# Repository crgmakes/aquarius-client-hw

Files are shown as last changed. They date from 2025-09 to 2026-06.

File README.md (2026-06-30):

# Aquarius Client Hardware

All the source files for the client hardware.

# Software 

You will need [KiCad](https://kicad.org) to view and edit this design. Click [here](https://www.kicad.org/download/) to download.

You will also need all the associated libraries and models to drive the design if you want to make changes or view the 3D rendering:

https://github.com/crgmakes/kicad-library.git

Kicad MUST be configured properly to use all the files in this repo. Once you have Kicad installed, under Preferences->Configure Paths..., make the following entries:

1 - KICAD_USER_DIR -> set to the root location of where you placed the above repository.
2 - KICAD_USER_LIBRARY = ${KICAD_USER_DIR}/Library
3 - KICAD_USER_MODEL_DIR = ${KICAD_USER_LIBRARY}/models
4 - KICAD_USER_TEMPLATE_DIR	= ${KICAD_USER_LIBRARY}/templates	

Kicad will operate mostly normally if these are not set properly. You will notice an issue when you view the PCB in 3D mode.

***NOTE***: after makeing a release build in git, if your rendered 3D images are missing components, ensure the path to EVERY component model is set to ${KICAD_USER_MODEL_DIR}/<model name>.

Kicad sometimes replaces the variable with an expansion and that FAILS during the build process because the expanded variable is local and does not match the build environment.

---

THE DESIGN IS PROVIDED "AS IS" AND THE AUTHOR DISCLAIMS ALL WARRANTIES WITH REGARD TO THIS DESIGN INCLUDING ALL IMPLIED WARRANTIES OF MERCHANTABILITY AND FITNESS. IN NO EVENT SHALL THE AUTHOR BE LIABLE FOR ANY SPECIAL, DIRECT, INDIRECT, OR CONSEQUENTIAL DAMAGES OR ANY DAMAGES WHATSOEVER RESULTING FROM LOSS OF USE, DATA OR PROFITS, WHETHER IN AN ACTION OF CONTRACT, NEGLIGENCE OR OTHER TORTIOUS ACTION, ARISING OUT OF OR IN CONNECTION WITH THE USE OR PERFORMANCE OF THIS DESIGN.

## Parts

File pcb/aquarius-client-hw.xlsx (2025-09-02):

Prj: | aquarius-client-hw.csv |  |  |  | Board Qty: | 100
Co.: |  |  |  |  | Unit Cost: | $0.00
Prj date: | 2025-09-01 11:43:55 (file) |  |  |  | Total Cost: | $0.00
$ date: | 2025-09-01 12:00:02
Global Part Info
Refs | Value | Footprint | Manf# | Qty | Unit$ | Ext$
C_0603_1608Metric#1 | ??? - p1/2 | ??? | C17 | 100
C_0603_1608Metric#2 | ??? - p2/2 | ??? | C18 | 100
D_SOD523#1 | ??? - p1/8 | ??? | D11 | 100
D_SOD523#2 | ??? - p2/8 | ??? | D12 | 100
D_SOD523#3 | ??? - p3/8 | ??? | D13 | 100
D_SOD523#4 | ??? - p4/8 | ??? | D14 | 100
D_SOD523#5 | ??? - p5/8 | ??? | D15 | 100
D_SOD523#6 | ??? - p6/8 | ??? | D16 | 100
D_SOD523#7 | ??? - p7/8 | ??? | D9 | 100
D_SOD523#8 | ??? - p8/8 | ??? | D10 | 100
EVQQ2B02W0#1 | ??? - p1/2 | ??? | SW2 | 100
EVQQ2B02W0#2 | ??? - p2/2 | ??? | SW1 | 100
GCT_USB4105-GF-A | ??? | ??? | J3 | 100
JST_SH_BM03B-SRSS-TB_1x03-1MP_P1.00mm_Vertical#1 | ??? - p1/10 | ??? | J2 | 100
JST_SH_BM03B-SRSS-TB_1x03-1MP_P1.00mm_Vertical#2 | ??? - p2/10 | ??? | J15 | 100
JST_SH_BM03B-SRSS-TB_1x03-1MP_P1.00mm_Vertical#3 | ??? - p3/10 | ??? | J16 | 100
JST_SH_BM03B-SRSS-TB_1x03-1MP_P1.00mm_Vertical#4 | ??? - p4/10 | ??? | J11 | 100
JST_SH_BM03B-SRSS-TB_1x03-1MP_P1.00mm_Vertical#5 | ??? - p5/10 | ??? | J12 | 100
JST_SH_BM03B-SRSS-TB_1x03-1MP_P1.00mm_Vertical#6 | ??? - p6/10 | ??? | J4 | 100
JST_SH_BM03B-SRSS-TB_1x03-1MP_P1.00mm_Vertical#7 | ??? - p7/10 | ??? | J14 | 100
JST_SH_BM03B-SRSS-TB_1x03-1MP_P1.00mm_Vertical#8 | ??? - p8/10 | ??? | J1 | 100
JST_SH_BM03B-SRSS-TB_1x03-1MP_P1.00mm_Vertical#9 | ??? - p9/10 | ??? | J10 | 100
JST_SH_BM03B-SRSS-TB_1x03-1MP_P1.00mm_Vertical#10 | ??? - p10/10 | ??? | J13 | 100
JST_SH_BM04B-SRSS-TB_1x04-1MP_P1.00mm_Vertical#1 | ??? - p1/4 | ??? | J5 | 100
JST_SH_BM04B-SRSS-TB_1x04-1MP_P1.00mm_Vertical#2 | ??? - p2/4 | ??? | J17 | 100
JST_SH_BM04B-SRSS-TB_1x04-1MP_P1.00mm_Vertical#3 | ??? - p3/4 | ??? | J18 | 100
JST_SH_BM04B-SRSS-TB_1x04-1MP_P1.00mm_Vertical#4 | ??? - p4/4 | ??? | J6 | 100
JST_SH_BM08B-SRSS-TB_1x08-1MP_P1.00mm_Vertical#1 | ??? - p1/2 | ??? | J19 | 100
JST_SH_BM08B-SRSS-TB_1x08-1MP_P1.00mm_Vertical#2 | ??? - p2/2 | ??? | J9 | 100
JST_SH_SM04B-SRSS-TB_1x04-1MP_P1.00mm_Horizontal#1 | ??? - p1/2 | ??? | J7 | 100
JST_SH_SM04B-SRSS-TB_1x04-1MP_P1.00mm_Horizontal#2 | ??? - p2/2 | ??? | J8 | 100
LED_0603_1608Metric#1 | ??? - p1/2 | ??? | D7 | 100
LED_0603_1608Metric#2 | ??? - p2/2 | ??? | D8 | 100
LED_WS2812B-2020_PLCC4_2.0x2.0mm | ??? | ??? | D1 | 100
LTR303ALS1 | ??? | ??? | U3 | 100
PWSONN6 | ??? | ??? | U2 | 100
R_0603_1608Metric | ??? | ??? | R9 | 100
SON80P244X244X95-7N | ??? | ??? | U8 | 100
SOT666 | ??? | ??? | U4 | 100
SOTFL50P160X60-8N#1 | ??? - p1/2 | ??? | U5 | 100
SOTFL50P160X60-8N#2 | ??? - p2/2 | ??? | U6 | 100
TO2522 | ??? | ??? | U9 | 100
KiCost® v1.1.20

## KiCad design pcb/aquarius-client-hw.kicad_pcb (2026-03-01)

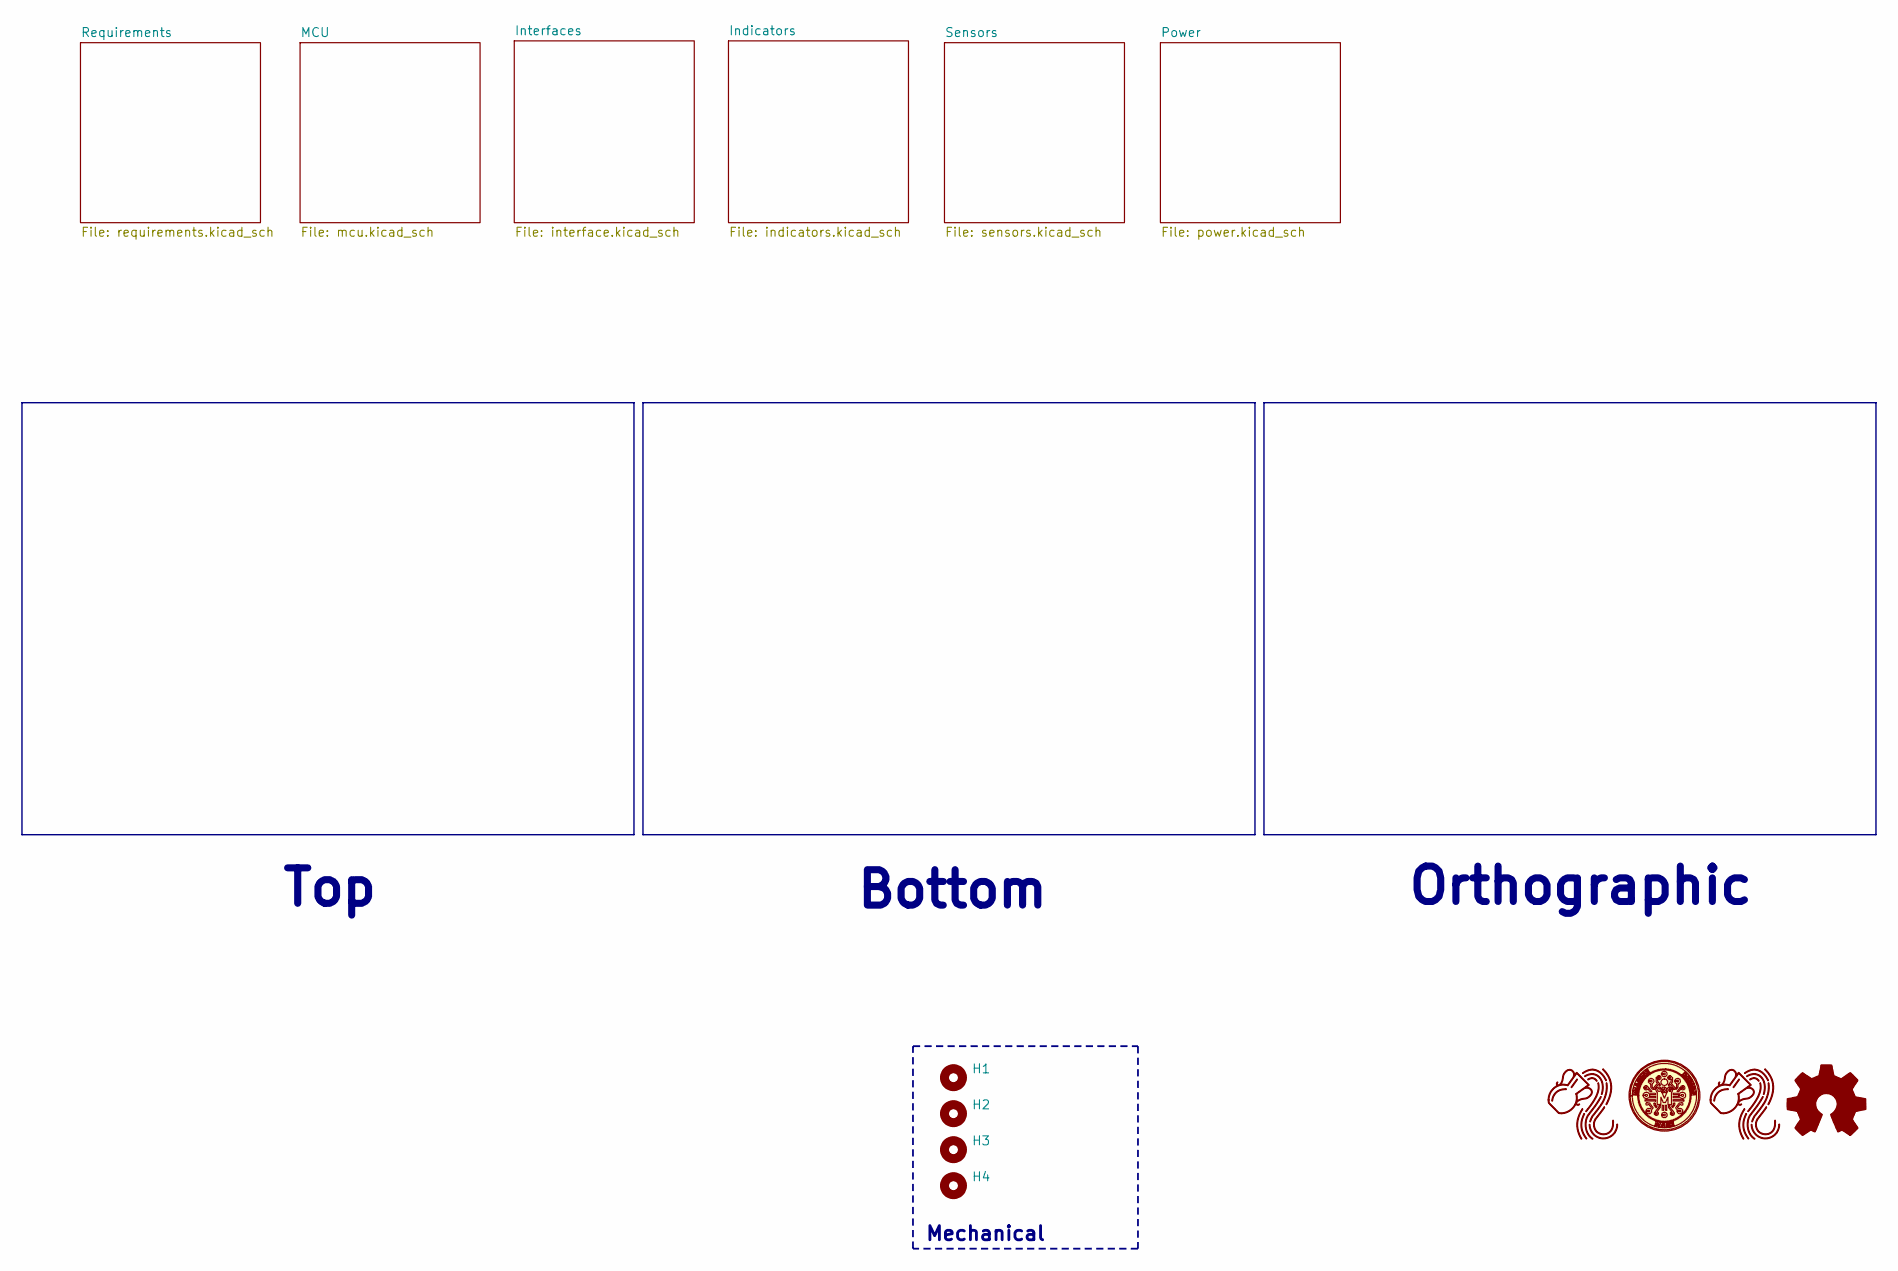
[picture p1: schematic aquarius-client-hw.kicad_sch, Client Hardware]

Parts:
H1, H2, H3, H4: MountingHole_3.2mm_M3_Pad_Via
LOGO1: CRGM Logo 5mm
LOGO2, LOGO3: Aquarius Logo 5mm
LOGO4: OSHW-Logo_5.7x6mm_SilkScreen

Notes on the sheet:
Mechanical
Bottom
Orthographic
Top

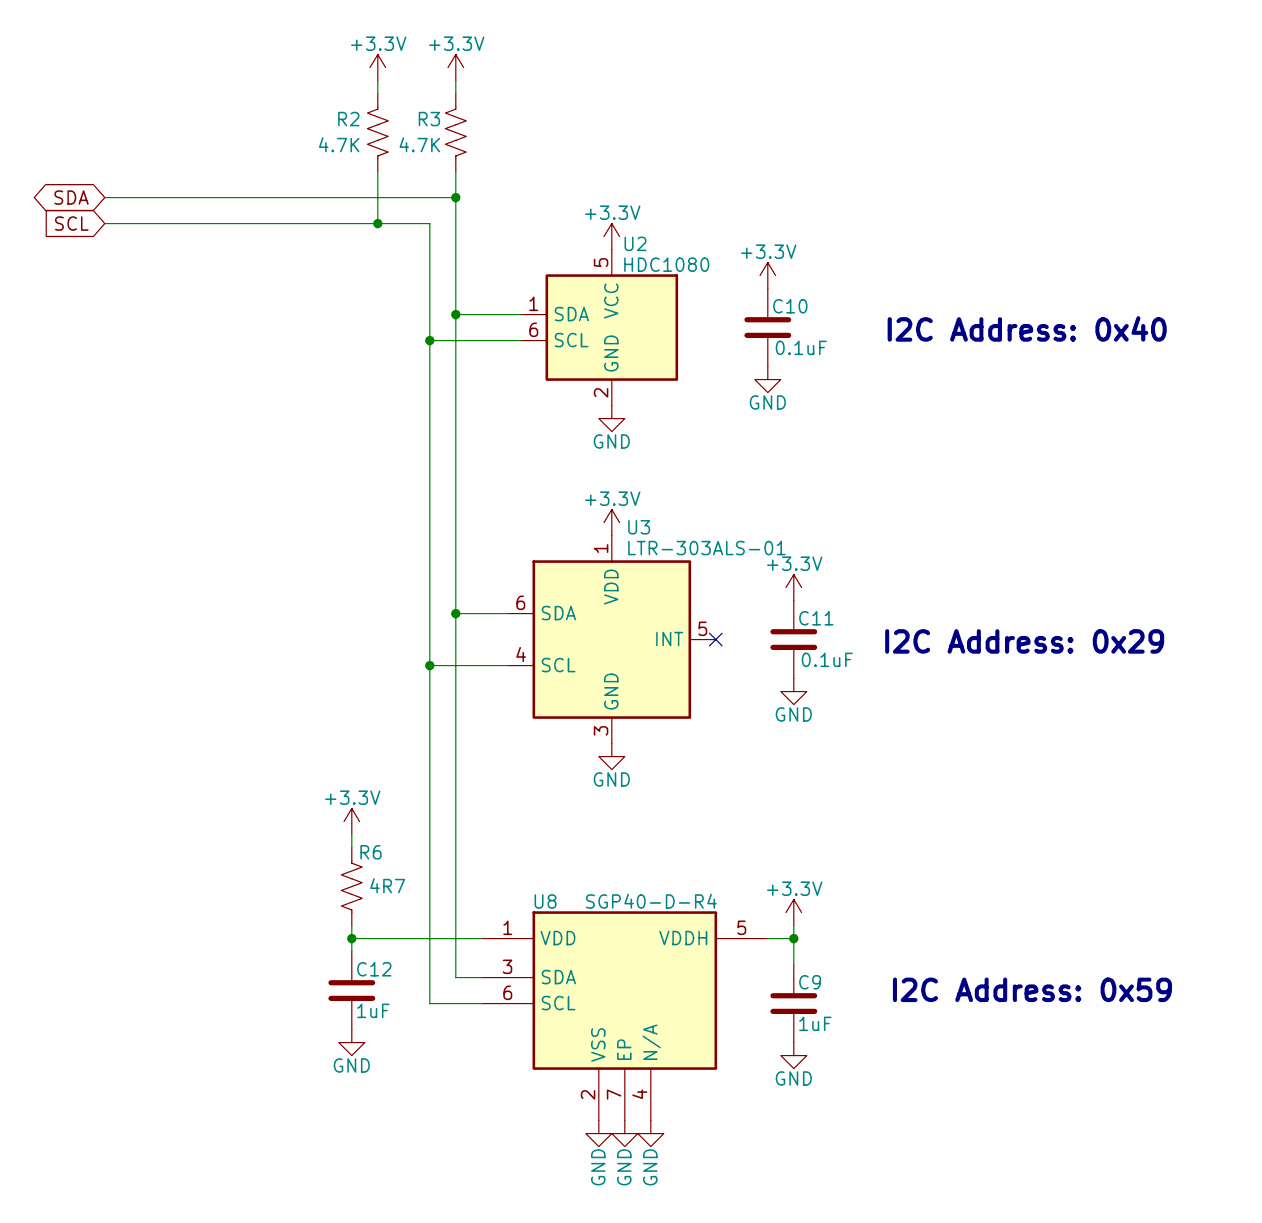
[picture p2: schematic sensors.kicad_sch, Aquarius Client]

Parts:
C9, C12: 1uF; C_0603_1608Metric; Tolerance 10%; MPN CGA0603X5R105K160JT; Mouser 187-CL10B105KO8NNNC
C10, C11: 0.1uF; C_0603_1608Metric; Tolerance 10%; MPN CL10B104KO8NNNC; Digikey 1276-1005-2-ND
R2: 4.7K; R_0603_1608Metric; Tolerance 5%; MPN FRC0603J472 TS; Mouser 652-CR0603-JW-472ELF
R3: 4.7K; R_0603_1608Metric; Tolerance 5%; MPN FRC0603J472 TS; LCSC C2907166
R6: 4R7; R_0603_1608Metric; Tolerance 5%; MPN FRC0603J4R7 TS; Mouser 652-CR0603JW-4R7ELF
U2: HDC1080; PWSON-N6; MPN HDC1080DMBR; Digikey 296-46272-2-ND
U3: LTR-303ALS-01; MPN LTR-303ALS-01; Digikey 160-2161-2-ND
U8: SGP40-D-R4; SON80P244X244X95-7N; MPN SGP40-D-R4; Digikey 1649-SGP40-D-R4TR-ND

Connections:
+3.3V: C9.1, C10.1, C11.1, R2.2, R3.2, R6.1, U2.5 (VCC), U3.1 (VDD), U8.5 (VDDH); also elsewhere on the board
GND: C9.2, C10.2, C11.2, C12.2, U2.2 (GND), U3.3 (GND), U8.2 (VSS), U8.4 (N/A), U8.7 (EP); also elsewhere on the board
unnamed: C12.1, R6.2, U8.1 (VDD)
SCL: R2.1, U2.6 (SCL), U3.4 (SCL), U8.6 (SCL); also elsewhere on the board
SDA: R3.1, U2.1 (SDA), U3.6 (SDA), U8.3 (SDA); also elsewhere on the board

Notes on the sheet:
I2C Address: 0x40
I2C Address: 0x29
I2C Address: 0x59

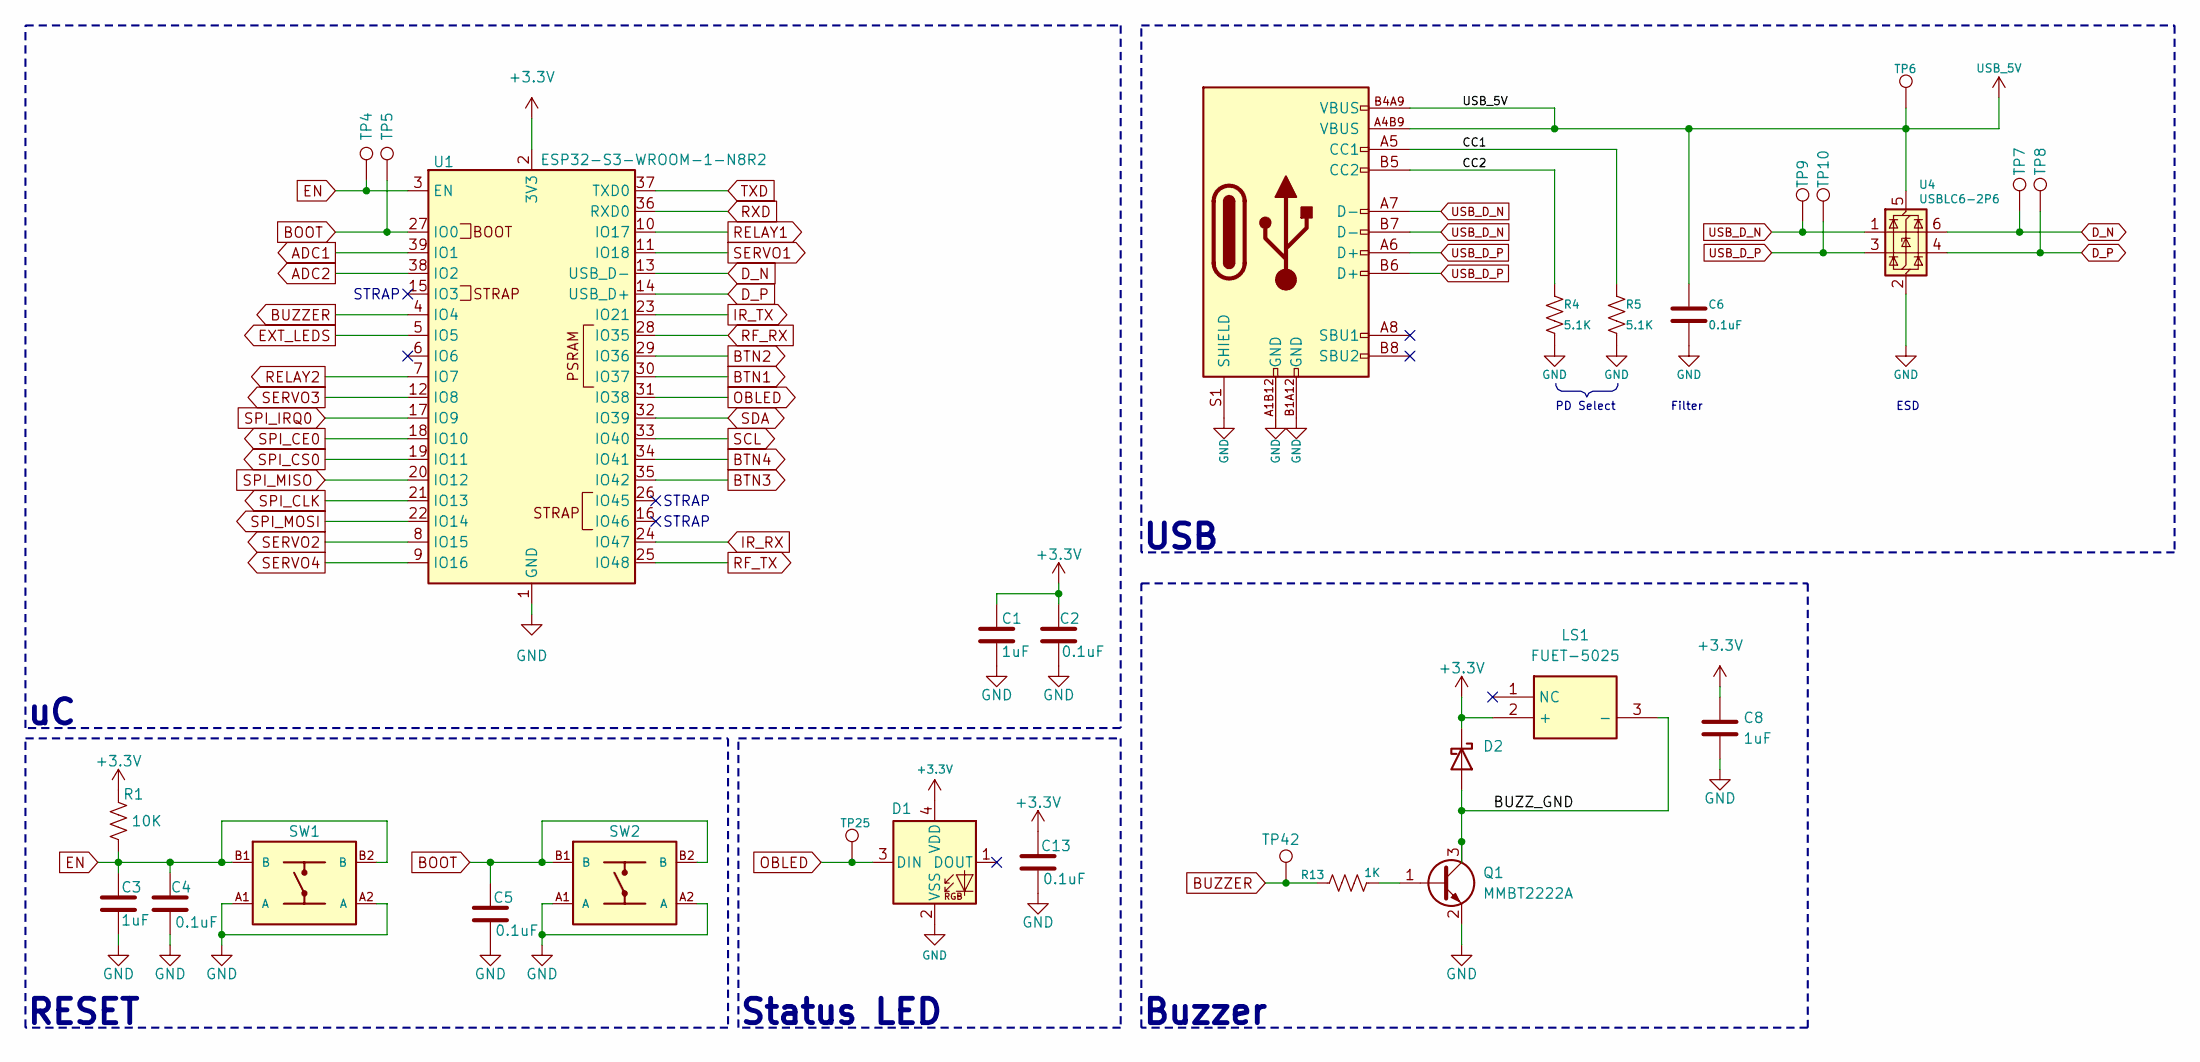
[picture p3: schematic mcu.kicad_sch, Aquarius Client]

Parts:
C1, C8: 1uF; C_0603_1608Metric; Tolerance 10%; MPN CGA0603X5R105K160JT; LCSC C6119849
C2, C6: 0.1uF; C_0603_1608Metric; Tolerance 10%; MPN CL10B104KO8NNNC; LCSC C66501
C3: 1uF; C_0603_1608Metric; Tolerance 10%; MPN CGA0603X5R105K160JT; Mouser 187-CL10B105KO8NNNC
C4: 0.1uF; C_0603_1608Metric; Tolerance 10%; MPN CL10B104KO8NNNC; Mouser 187-CL10B104KO8NNNC
C5, C13: 0.1uF; C_0603_1608Metric; Tolerance 10%; MPN CL10B104KO8NNNC; Digikey 1276-1005-2-ND
D1: WS2812B-2020; LED_WS2812B-2020_PLCC4_2.0x2.0mm; MPN WS2812C-2020-V1; LCSC C2976072
D2: D_Schottky; D_SOD-523; MPN MSK4010; LCSC C345958
J3: USB_C_USB2.0_16P; GCT_USB4105-GF-A; MPN USB4105-GF-A-060; Mouser 640-USB4105-GF-A-060
LS1: FUET-5025; MPN FUET-5025; Mouser 490-CMT-0502-75SMTTR
Q1: MMBT2222A; SOT-523; MPN MMBT2222AT-7-F; Mouser 621-MMBT2222AT-F
R1: 10K; R_0603_1608Metric; Tolerance 5%; MPN FRC0603J103TS; Mouser 652-CR0603-JW-103ELF
R4, R5: 5.1K; R_0603_1608Metric; Tolerance 5%; MPN FRC0603J512 TS; Mouser 652-CR0603JW-512ELF
R13: 1K; R_0603_1608Metric; Tolerance 5%; MPN FRC0603J102 TS; LCSC C2907113
SW1, SW2: EVQ-Q2B02W; MPN EVQ-Q2B02W; Mouser 667-EVQ-Q2B02W
TP4, TP5, TP6, TP7, TP8, TP9, TP10, TP25, TP42: TestPoint_Pad_D1.0mm
U1: ESP32-S3-WROOM-1-N8R2; MPN ESP32-S3-WROOM-1-N8R2; Mouser 356-ESP32-S3WRM1N8R2
U4: USBLC6-2P6; SOT-666; MPN USBLC6-2P6; LCSC C2827693

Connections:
+3.3V: C1.1, C2.1, C8.1, C13.1, D1.4 (VDD), D2.1 (K), LS1.2 (+), R1.1, U1.2 (3V3); also elsewhere on the board
/MCU/BUZZ_GND: D2.2 (A), LS1.3 (-), Q1.3 (C)
/MCU/CC1: J3.A5 (CC1), R5.1
/MCU/CC2: J3.B5 (CC2), R4.1
ADC1: U1.39 (IO1); also elsewhere on the board
ADC2: U1.38 (IO2); also elsewhere on the board
BOOT: C5.1, SW2.B1 (B), SW2.B2 (B), TP5.1, U1.27 (IO0)
BTN1: U1.30 (IO37); also elsewhere on the board
BTN2: U1.29 (IO36); also elsewhere on the board
BTN3: U1.35 (IO42); also elsewhere on the board
BTN4: U1.34 (IO41); also elsewhere on the board
BUZZER: R13.1, TP42.1, U1.4 (IO4)
D_N: TP7.1, U1.13 (USB_D-), U4.6 (I/O1)
D_P: TP8.1, U1.14 (USB_D+), U4.4 (I/O2)
EN: C3.1, C4.1, R1.2, SW1.B1 (B), SW1.B2 (B), TP4.1, U1.3 (EN)
EXT_LEDS: U1.5 (IO5); also elsewhere on the board
GND: C1.2, C2.2, C3.2, C4.2, C5.2, C6.2, C8.2, C13.2, D1.2 (VSS), J3.A1B12 (GND), J3.B1A12 (GND), J3.S1 (SHIELD), Q1.2 (E), R4.2, R5.2, SW1.A1 (A), SW1.A2 (A), SW2.A1 (A), SW2.A2 (A), U1.1 (GND), U1.40 (GND), U1.41 (GND), U4.2 (GND); also elsewhere on the board
IR_RX: U1.24 (IO47); also elsewhere on the board
IR_TX: U1.23 (IO21); also elsewhere on the board
unnamed: Q1.1 (B), R13.2
OBLED: D1.3 (DIN), TP25.1, U1.31 (IO38)
RELAY1: U1.10 (IO17); also elsewhere on the board
RELAY2: U1.7 (IO7); also elsewhere on the board
RF_RX: U1.28 (IO35); also elsewhere on the board
RF_TX: U1.25 (IO48); also elsewhere on the board
RXD: U1.36 (RXD0); also elsewhere on the board
SCL: U1.33 (IO40); also elsewhere on the board
SDA: U1.32 (IO39); also elsewhere on the board
SERVO1: U1.11 (IO18); also elsewhere on the board
SERVO2: U1.8 (IO15); also elsewhere on the board
SERVO3: U1.12 (IO8); also elsewhere on the board
SERVO4: U1.9 (IO16); also elsewhere on the board
SPI_CE0: U1.18 (IO10); also elsewhere on the board
SPI_CLK: U1.21 (IO13); also elsewhere on the board
SPI_CS0: U1.19 (IO11); also elsewhere on the board
SPI_IRQ0: U1.17 (IO9); also elsewhere on the board
SPI_MISO: U1.20 (IO12); also elsewhere on the board
SPI_MOSI: U1.22 (IO14); also elsewhere on the board
TXD: U1.37 (TXD0); also elsewhere on the board
USB_5V: C6.1, J3.A4B9 (VBUS), J3.B4A9 (VBUS), TP6.1, U4.5 (VBUS); also elsewhere on the board
USB_D_N: J3.A7 (D-), J3.B7 (D-), TP9.1, U4.1 (I/O1)
USB_D_P: J3.A6 (D+), J3.B6 (D+), TP10.1, U4.3 (I/O2)

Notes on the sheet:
RESET
STRAP
Buzzer
Filter
Status LED
PD Select
ESD
USB

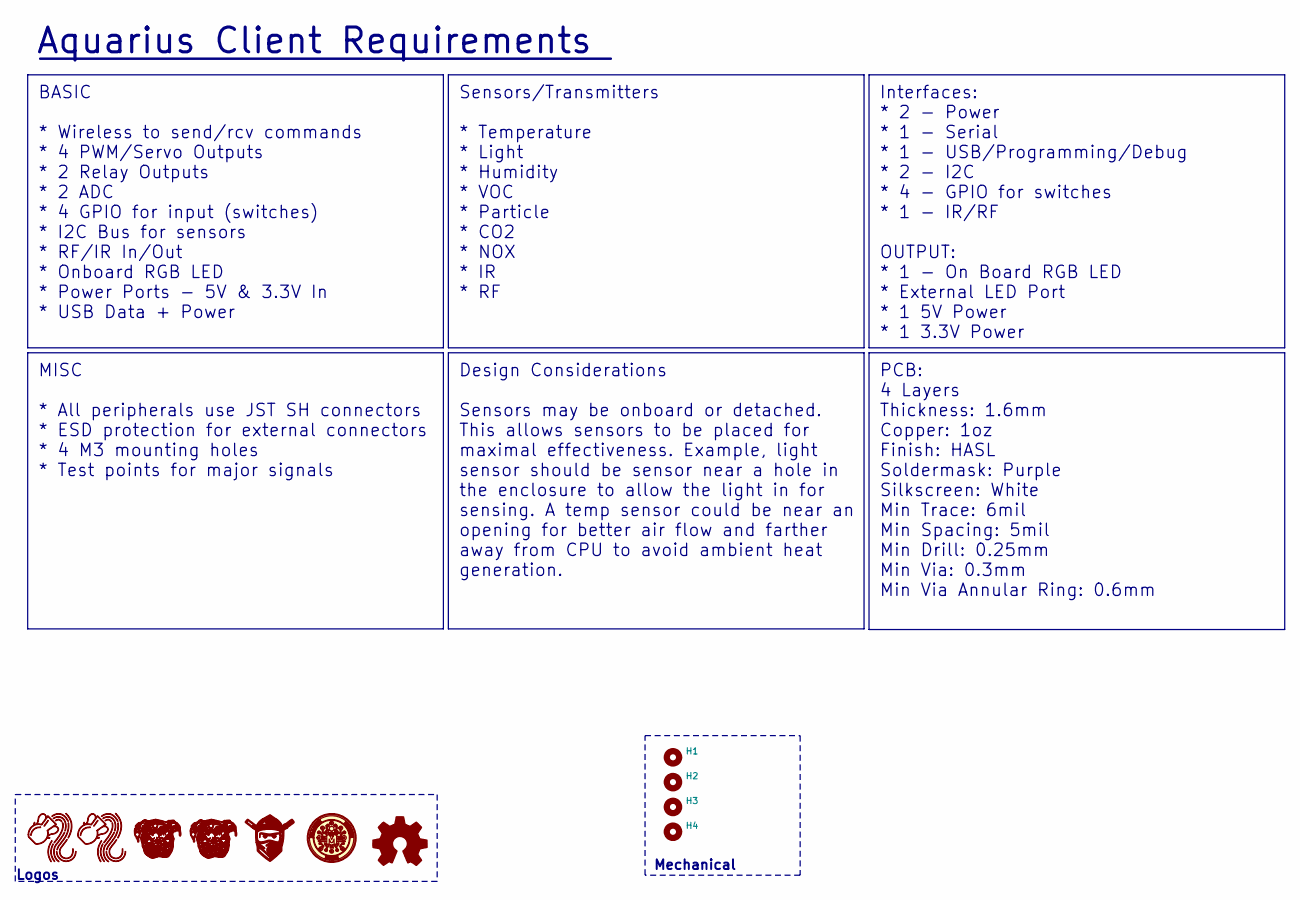
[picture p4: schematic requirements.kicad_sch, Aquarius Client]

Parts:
H1, H2, H3, H4: MountingHole_3.2mm_M3_Pad_Via
LOGO1: CRGM Logo 10mm
LOGO2: Aquarius Logo 5mm
LOGO3: Aquarius Logo 8mm
LOGO4: OSHW-Logo_5.7x6mm_SilkScreen
LOGO5: Roxy 6.5mm
LOGO6: Roxy 8mm
LOGO7: FNWW Face 5mm

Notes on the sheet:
Logos
Mechanical
Aquarius Client Requirements
Design Considerations Sensors may be onboard or detached. This allows sensors to be placed for maximal effectiveness. Example, light sensor should be sensor near a hole in the enclosure to allow the light in for sensing. A temp sensor could be near an opening for better air flow and farther away fr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
BASIC * Wireless to send/rcv commands * 4 PWM/Servo Outputs * 2 Relay Outputs * 2 ADC * 4 GPIO for input (switches) * I2C Bus for sensors * RF/IR In/Out * Onboard RGB LED * Power Ports - 5V & 3.3V In * USB Data + Power
Interfaces: * 2 - Power * 1 - Serial * 1 - USB/Programming/Debug * 2 - I2C * 4 - GPIO for switches * 1 - IR/RF OUTPUT: * 1 - On Board RGB LED * External LED Port * 1 5V Power * 1 3.3V Power
MISC * All peripherals use JST SH connectors * ESD protection for external connectors * 4 M3 mounting holes * Test points for major signals
PCB: 4 Layers Thickness: 1.6mm Copper: 1oz Finish: HASL Soldermask: Purple Silkscreen: White Min Trace: 6mil Min Spacing: 5mil Min Drill: 0.25mm Min Via: 0.3mm Min Via Annular Ring: 0.6mm
Sensors/Transmitters * Temperature * Light * Humidity * VOC * Particle * CO2 * NOX * IR * RF

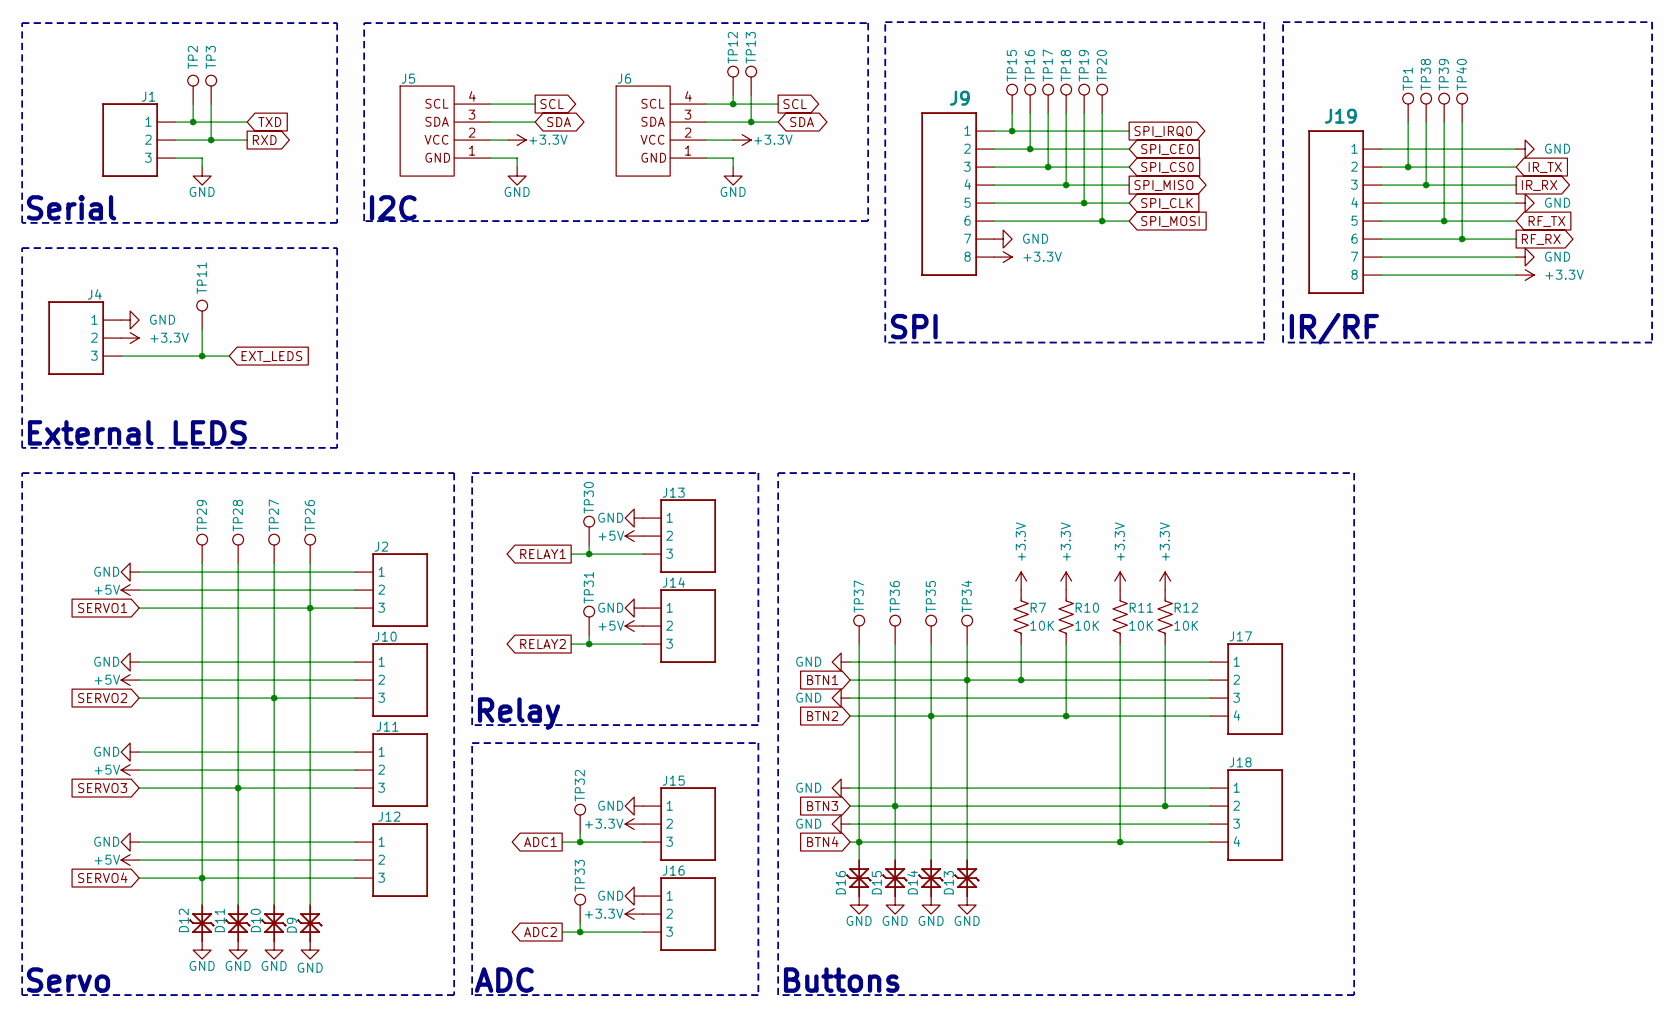
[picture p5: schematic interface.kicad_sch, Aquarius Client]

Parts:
D9, D10, D11, D12, D13, D14, D15, D16: PESD5V0S1BB; D_SOD-523; MPN PESD5V0S1BB,115; LCSC C314264
J1, J2, J4, J10, J11, J12, J13, J14, J15, J16: JST_SH_BM03B-SRSS-TB_1x03-1MP_P1.00mm_Vertical; MPN BM03B-SRSS-TB; LCSC C2904985
J5, J6, J17, J18: JST_SH_BM04B-SRSS-TB_1x04-1MP_P1.00mm_Vertical; MPN BM04B-SRSS-TBT(LF)(SN); Mouser 306-BM04BSRSSTBTLFSN
J9, J19: JST_SH_BM08B-SRSS-TB_1x08-1MP_P1.00mm_Vertical; MPN BM08B-SRSS-TB(LF)(SN); LCSC C2845376
R7, R10, R11, R12: 10K; R_0603_1608Metric; Tolerance 5%; MPN FRC0603J103TS; LCSC C2930027
TP1, TP2, TP3, TP11, TP12, TP13, TP15, TP16, TP17, TP18, TP19, TP20, TP26, TP27, TP28, TP29, TP30, TP31, TP32, TP33, TP34, TP35, TP36, TP37, TP38, TP39, TP40: TestPoint_Pad_D1.0mm

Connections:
+3.3V: J4.2, J5.2, J6.2, J9.8, J15.2, J16.2, J19.8, R7.1, R10.1, R11.1, R12.1; also elsewhere on the board
+5V: J2.2, J10.2, J11.2, J12.2, J13.2, J14.2; also elsewhere on the board
ADC1: J15.3, TP32.1; also elsewhere on the board
ADC2: J16.3, TP33.1; also elsewhere on the board
BTN1: D13.2 (K2), J17.2, R7.2, TP34.1; also elsewhere on the board
BTN2: D14.2 (K2), J17.4, R10.2, TP35.1; also elsewhere on the board
BTN3: D15.2 (K2), J18.2, R12.2, TP36.1; also elsewhere on the board
BTN4: D16.2 (K2), J18.4, R11.2, TP37.1; also elsewhere on the board
EXT_LEDS: J4.3, TP11.1; also elsewhere on the board
GND: D9.1 (K1), D10.1 (K1), D11.1 (K1), D12.1 (K1), D13.1 (K1), D14.1 (K1), D15.1 (K1), D16.1 (K1), J1.3, J2.1, J4.1, J5.1, J6.1, J9.7, J10.1, J11.1, J12.1, J13.1, J14.1, J15.1, J16.1, J17.1, J17.3, J18.1, J18.3, J19.1, J19.4, J19.7; also elsewhere on the board
IR_RX: J19.3, TP38.1; also elsewhere on the board
IR_TX: J19.2, TP1.1; also elsewhere on the board
RELAY1: J13.3, TP30.1; also elsewhere on the board
RELAY2: J14.3, TP31.1; also elsewhere on the board
RF_RX: J19.6, TP40.1; also elsewhere on the board
RF_TX: J19.5, TP39.1; also elsewhere on the board
RXD: J1.2, TP3.1; also elsewhere on the board
SCL: J5.4, J6.4, TP12.1; also elsewhere on the board
SDA: J5.3, J6.3, TP13.1; also elsewhere on the board
SERVO1: D9.2 (K2), J2.3, TP26.1; also elsewhere on the board
SERVO2: D10.2 (K2), J10.3, TP27.1; also elsewhere on the board
SERVO3: D11.2 (K2), J11.3, TP28.1; also elsewhere on the board
SERVO4: D12.2 (K2), J12.3, TP29.1; also elsewhere on the board
SPI_CE0: J9.2, TP16.1; also elsewhere on the board
SPI_CLK: J9.5, TP19.1; also elsewhere on the board
SPI_CS0: J9.3, TP17.1; also elsewhere on the board
SPI_IRQ0: J9.1, TP15.1; also elsewhere on the board
SPI_MISO: J9.4, TP18.1; also elsewhere on the board
SPI_MOSI: J9.6, TP20.1; also elsewhere on the board
TXD: J1.1, TP2.1; also elsewhere on the board

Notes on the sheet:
ADC
Serial
External LEDS
Buttons
Servo
IR/RF
Relay
I2C
SPI

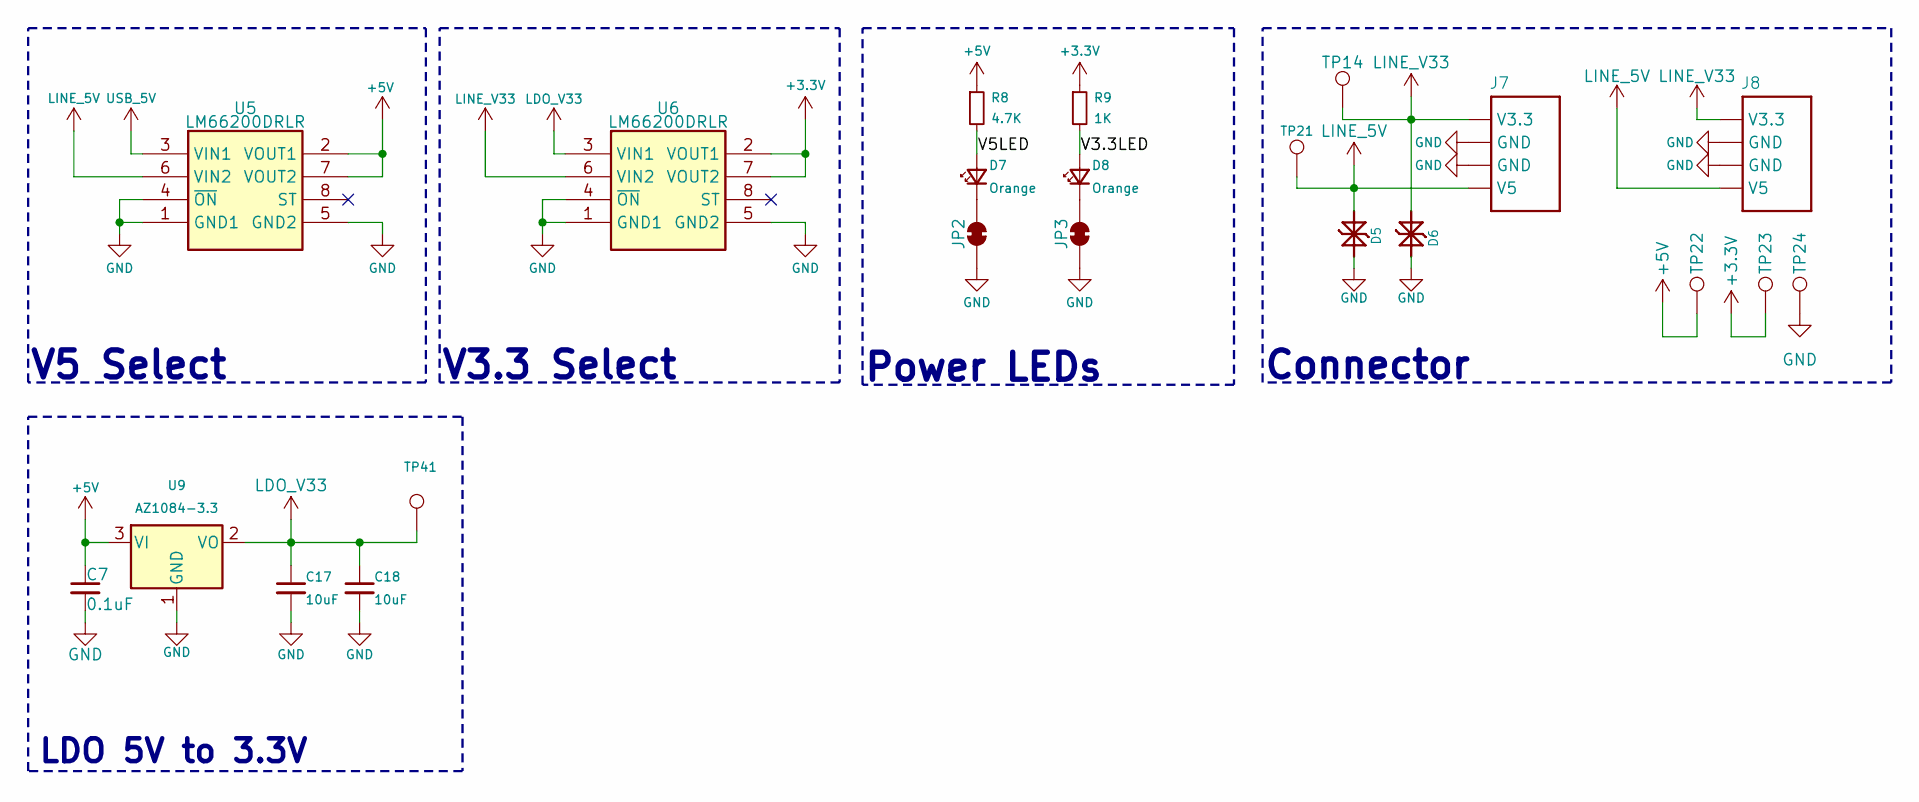
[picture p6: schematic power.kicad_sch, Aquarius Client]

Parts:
C7: 0.1uF; C_0603_1608Metric; Tolerance 10%; MPN CL10B104KO8NNNC; LCSC C66501
C17, C18: 10uF; C_0603_1608Metric; Tolerance 10%; MPN CL10A106MO8NQNC; Mouser 187-CL10A106MO8NQNC
D5: PESD5V5C1BL; DFN1006-2; MPN PESD5V5C1BLYL; LCSC C2827636
D6: PESD3V3S1BL; DFN1006-2; MPN LESD8D3.3CAT5G; LCSC C5563754
D7, D8: Orange; LED_0603_1608Metric; MPN XL-1608UOC-06; Mouser 859-LTST-C190KFKT
J7, J8: JST_SH_SM04B-SRSS-TB_1x04-1MP_P1.00mm_Horizontal; MPN SM04B-SRSS-TBT(LF)(SN); LCSC C2763614
JP2, JP3: SolderJumper-2_P1.3mm_Bridged_RoundedPad1.0x1.5mm
R8: 4.7K; R_0603_1608Metric; Tolerance 5%; MPN FRC0603J472 TS; Mouser 652-CR0603-JW-472ELF
R9: 1K; R_0603_1608Metric; Tolerance 5%; MPN FRC0603J102 TS; Mouser 652-CR0603-JW-102ELF
TP14, TP21, TP22, TP23, TP24, TP41: TestPoint_Pad_D1.0mm
U5, U6: LM66200DRLR; SOTFL50P160X60-8N; MPN LM66200DRLR; Mouser 595-LM66200DRLR
U9: AZ1084-3.3; TO-252-2; MPN AZ1084CD-3.3TRG1; Mouser 621-AZ1084CD-3.3TRG1

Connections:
+3.3V: R9.1, TP23.1, U6.2 (VOUT1), U6.7 (VOUT2); also elsewhere on the board
+5V: C7.1, R8.1, TP22.1, U5.2 (VOUT1), U5.7 (VOUT2), U9.3 (VI); also elsewhere on the board
/Power/V3.3LED: D8.2 (A), R9.2
/Power/V5LED: D7.2 (A), R8.2
GND: C7.2, C17.2, C18.2, D5.1 (K1), D6.1 (K1), J7.2 (GND), J7.3 (GND), J8.2 (GND), J8.3 (GND), JP2.1 (A), JP3.1 (A), TP24.1, U5.1 (GND1), U5.4 (~ON), U5.5 (GND2), U6.1 (GND1), U6.4 (~ON), U6.5 (GND2), U9.1 (GND); also elsewhere on the board
LDO_V33: C17.1, C18.1, TP41.1, U6.3 (VIN1), U9.2 (VO)
LINE_5V: D5.2 (K2), J7.1 (V5), J8.1 (V5), TP21.1, U5.6 (VIN2)
LINE_V33: D6.2 (K2), J7.4 (V3.3), J8.4 (V3.3), TP14.1, U6.6 (VIN2)
unnamed: D7.1 (K), JP2.2 (B)
unnamed: D8.1 (K), JP3.2 (B)
USB_5V: U5.3 (VIN1); also elsewhere on the board

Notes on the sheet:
Connector
Power LEDs
V3.3 Select
V5 Select
LDO 5V to 3.3V

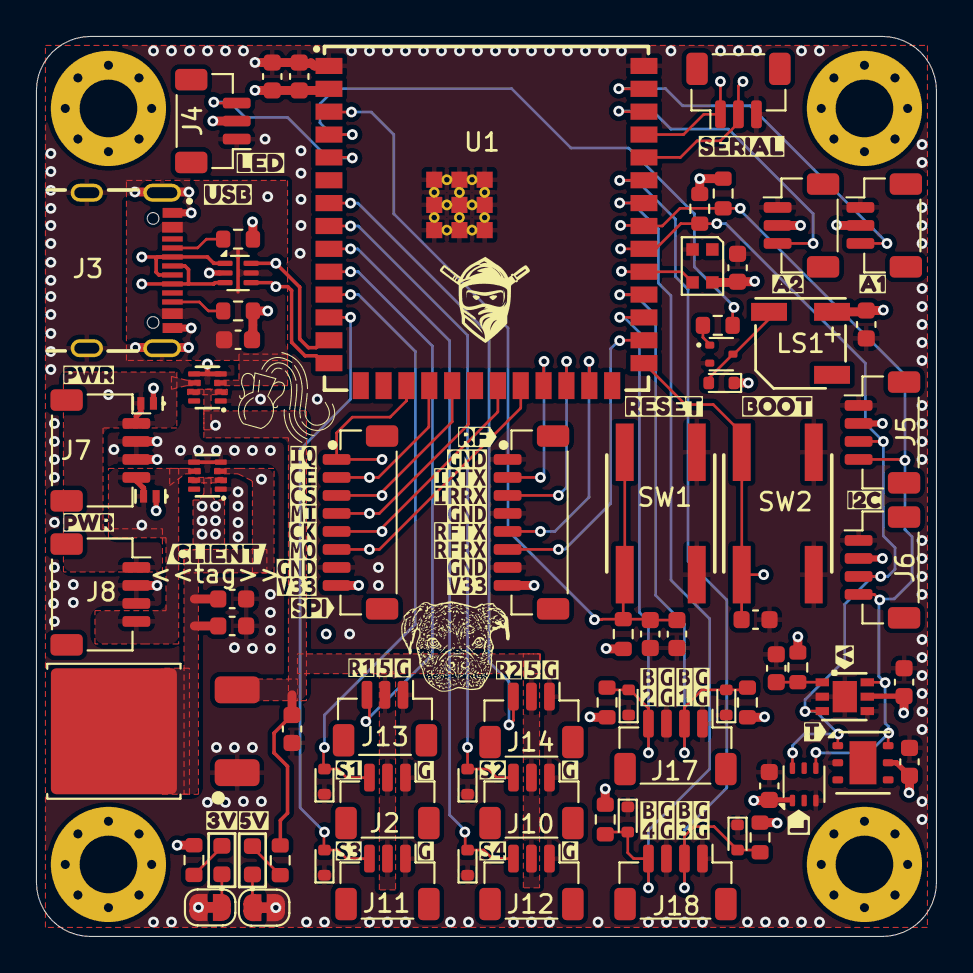
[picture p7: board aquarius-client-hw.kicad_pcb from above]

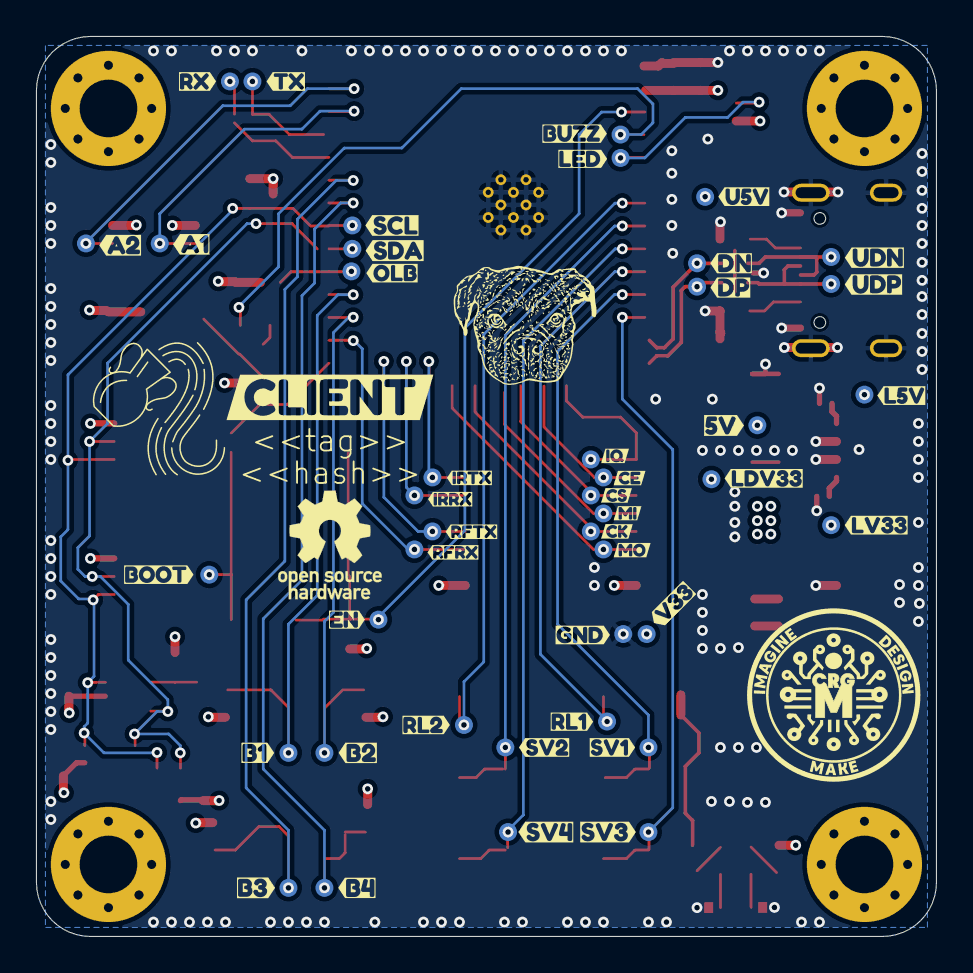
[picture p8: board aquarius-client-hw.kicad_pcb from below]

Board: 4 copper layers, 50.0 x 50.0 mm, 227 parts (89 on the bottom side), 51 nets.

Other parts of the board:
kibuzzard-68A7E28F: G***; kibuzzard-68A7E28F
kibuzzard-68A7E307: G***; kibuzzard-68A7E307
kibuzzard-68A7E319: G***; kibuzzard-68A7E319
kibuzzard-68A7E323: G***; kibuzzard-68A7E323
kibuzzard-68A7E330: G***; kibuzzard-68A7E330
kibuzzard-68A7E335: G***; kibuzzard-68A7E335
kibuzzard-68B3A65F: G***; kibuzzard-68B3A65F
kibuzzard-68B3A654: G***; kibuzzard-68B3A654
kibuzzard-68B3AA1F: G***; kibuzzard-68B3AA1F
kibuzzard-68B3AA17: G***; kibuzzard-68B3AA17
kibuzzard-68B3AA32: G***; kibuzzard-68B3AA32
kibuzzard-68B3AC3B: G***; kibuzzard-68B3AC3B
kibuzzard-68B3AC4B: G***; kibuzzard-68B3AC4B
kibuzzard-68B3AC5A, kibuzzard-68B3AC5A#2: G***; kibuzzard-68B3AC5A
kibuzzard-68B3AC9E: G***; kibuzzard-68B3AC9E
kibuzzard-68B3AC33: G***; kibuzzard-68B3AC33
kibuzzard-68B3AC43: G***; kibuzzard-68B3AC43
kibuzzard-68B3AC53: G***; kibuzzard-68B3AC53
kibuzzard-68B3AC63: G***; kibuzzard-68B3AC63
kibuzzard-68B3ACA6: G***; kibuzzard-68B3ACA6
kibuzzard-68B3ACAD: G***; kibuzzard-68B3ACAD
kibuzzard-68B3ACBE: G***; kibuzzard-68B3ACBE
kibuzzard-68B3ACD0: G***; kibuzzard-68B3ACD0
kibuzzard-68B3ACDE: G***; kibuzzard-68B3ACDE
kibuzzard-68B3ACEE: G***; kibuzzard-68B3ACEE
kibuzzard-68B3ACFB: G***; kibuzzard-68B3ACFB
kibuzzard-68B3ADFB: G***; kibuzzard-68B3ADFB
kibuzzard-68B36A6C: G***; kibuzzard-68B36A6C
kibuzzard-68B65F3B: G***; kibuzzard-68B65F3B
kibuzzard-68B65F21: G***; kibuzzard-68B65F21
kibuzzard-68B65F32: G***; kibuzzard-68B65F32
kibuzzard-68B65F42: G***; kibuzzard-68B65F42
kibuzzard-68B65FD7: G***; kibuzzard-68B65FD7
kibuzzard-68B65FE2: G***; kibuzzard-68B65FE2
kibuzzard-68B65FE9: G***; kibuzzard-68B65FE9
kibuzzard-68B65FF0: G***; kibuzzard-68B65FF0
kibuzzard-68B366B4: G***; kibuzzard-68B366B4
kibuzzard-68B368E2: G***; kibuzzard-68B368E2
kibuzzard-68B368ED: G***; kibuzzard-68B368ED
kibuzzard-68B368FE: G***; kibuzzard-68B368FE
kibuzzard-68B662DC: G***; kibuzzard-68B662DC
kibuzzard-68B662E3: G***; kibuzzard-68B662E3
kibuzzard-68B662EF: G***; kibuzzard-68B662EF
kibuzzard-68B662F4: G***; kibuzzard-68B662F4
kibuzzard-68B662FC: G***; kibuzzard-68B662FC
kibuzzard-68B3677E: G***; kibuzzard-68B3677E
kibuzzard-68B6602D: G***; kibuzzard-68B6602D
kibuzzard-68B6603D: G***; kibuzzard-68B6603D
kibuzzard-68B6630C: G***; kibuzzard-68B6630C
kibuzzard-68B36906: G***; kibuzzard-68B36906
kibuzzard-68B66007: G***; kibuzzard-68B66007
kibuzzard-68B66036: G***; kibuzzard-68B66036
kibuzzard-68B66042: G***; kibuzzard-68B66042
kibuzzard-68B66048: G***; kibuzzard-68B66048
kibuzzard-68B66302: G***; kibuzzard-68B66302
kibuzzard-68B66307: G***; kibuzzard-68B66307
kibuzzard-68BB9AB6: G***; kibuzzard-68BB9AB6
kibuzzard-68BB9ABD: G***; kibuzzard-68BB9ABD
kibuzzard-68BB9B03: G***; kibuzzard-68BB9B03
kibuzzard-68BC2B7D: G***; kibuzzard-68BC2B7D
kibuzzard-68BC3B7F: G***; kibuzzard-68BC3B7F
kibuzzard-68BC3B9C: G***; kibuzzard-68BC3B9C
kibuzzard-68BC3BAC: G***; kibuzzard-68BC3BAC
kibuzzard-68BC3EA3: G***; kibuzzard-68BC3EA3
kibuzzard-68BC3EAA: G***; kibuzzard-68BC3EAA
kibuzzard-68BC29E0: G***; kibuzzard-68BC29E0
kibuzzard-68BC210E: G***; kibuzzard-68BC210E
kibuzzard-68BC211C: G***; kibuzzard-68BC211C
kibuzzard-68BC213E: G***; kibuzzard-68BC213E
kibuzzard-68BC215D: G***; kibuzzard-68BC215D
kibuzzard-68BC217F: G***; kibuzzard-68BC217F
kibuzzard-68BC218D: G***; kibuzzard-68BC218D
kibuzzard-68BC2102: G***; kibuzzard-68BC2102
kibuzzard-68BC2127: G***; kibuzzard-68BC2127
kibuzzard-68BC2137: G***; kibuzzard-68BC2137
kibuzzard-68BC2167: G***; kibuzzard-68BC2167
kibuzzard-68BC2179: G***; kibuzzard-68BC2179
kibuzzard-68BC2187: G***; kibuzzard-68BC2187
kibuzzard-68BC2328: G***; kibuzzard-68BC2328
kibuzzard-689A6C29: G***; kibuzzard-689A6C29
kibuzzard-690A7D58: G***; kibuzzard-690A7D58
kibuzzard-6812E3A0: G***; kibuzzard-6812E3A0
kibuzzard-6812E3AD: G***; kibuzzard-6812E3AD
kibuzzard-6812E3BB: G***; kibuzzard-6812E3BB
kibuzzard-6812E3C5: G***; kibuzzard-6812E3C5
kibuzzard-6812E37E: G***; kibuzzard-6812E37E
kibuzzard-6812E420: G***; kibuzzard-6812E420
kibuzzard-6894D76E: G***; kibuzzard-6894D76E
kibuzzard-68927E88: G***; kibuzzard-68927E88
kibuzzard-68927E94: G***; kibuzzard-68927E94
kibuzzard-68927EA7: G***; kibuzzard-68927EA7
kibuzzard-68927EAF: G***; kibuzzard-68927EAF
kibuzzard-68953D9F: G***; kibuzzard-68953D9F
kibuzzard-68953DBA: G***; kibuzzard-68953DBA
kibuzzard-68953DE5: G***; kibuzzard-68953DE5
kibuzzard-68953DED: G***; kibuzzard-68953DED
kibuzzard-68953E7E: G***; kibuzzard-68953E7E
kibuzzard-68953F10: G***; kibuzzard-68953F10

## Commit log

2025-07-13 Initial checkin
    [env-module.kicad_pcb, env-module.kicad_sch, i2c_interface.kicad_sch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]
2025-07-24 Updated license and implemented RP2040
    [env-module.kicad_pcb, env-module.kicad_sch, indicators.kicad_sch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]
2025-08-11 Added interfaces and fully routed PCB
    [env-module.kicad_pcb, env-module.kicad_sch, i2c_interface.kicad_sch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]
2025-08-12 Change schematic name
    [env-module.kicad_pcb, env-module.kicad_sch, indicators.kicad_sch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]
2025-08-12 Changed name to client
    [aquarius-client-hw.kicad_pcb, aquarius-client-hw.kicad_sch, env-module.kicad_pcb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]
2025-08-12 Updated project name and properties
    [aquarius-client-hw.kicad_pcb, aquarius-client-hw.kicad_sch, indicators.kicad_sch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]
2025-08-12 Added labels for LEDs
    [aquarius-client-hw.kicad_pcb]
2025-08-12 Fixed offset for connectors
    [aquarius-client-hw.kicad_pcb]
2025-08-16 Switch cap/res to CRGM footprint
    [aquarius-client-hw.kicad_pcb, indicators.kicad_sch, mcu.kicad_sch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]
2025-08-22 Added button inputs and pull ups
    [interface.kicad_sch, mcu.kicad_sch]
2025-08-25 Added renders and aligned connectors
    Added renders
    Aligned connectors to grid
    Added dimensions
    Fixed part numbers and values
    [indicators.kicad_sch, interface.kicad_sch, mcu.kicad_sch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]
2025-08-26 Updated descriptions; fixed MN
    [mcu.kicad_sch, power.kicad_sch, sensors.kicad_sch]
2025-08-28 Fixed title name and panel props
    * Fixed title name
    * Fixed panel props
    * Updated descriptions
    * Updated fab properties
    [interface.kicad_sch, mcu.kicad_sch]
2025-08-31 Added RF connector; re-placed and re-routed
    [indicators.kicad_sch, interface.kicad_sch, mcu.kicad_sch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]
2025-09-01 Removed indictors sheet
    Fixed attribute consistency with schematic and symbols
    Moved logos to separate box
    Updated DRC warnings/ignore
    [indicators.kicad_sch, interface.kicad_sch, mcu.kicad_sch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]
2025-09-02 Added dimensions
    [aquarius-client-hw.xlsx]
2025-09-06 Added buzzer
    Added buzzer
    Fixed models
    Updated images
    [mcu.kicad_sch, requirements.kicad_sch]
2025-09-06 Added buzzer; fixed models
    Updated renders
    [mcu.kicad_sch]
2025-09-08 Updated part attributes for consistency
    [aquarius-client-hw.kicad_pcb, interface.kicad_sch, mcu.kicad_sch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]
2025-09-09 fixed LCSC part numbers
    [aquarius-client-hw.kicad_pcb, interface.kicad_sch]
2025-11-02 Updated LTR address to 0x40 rather than 0x80
    [sensors.kicad_sch]
2025-11-05 Updated LED footprint
    [aquarius-client-hw.kicad_pcb, power.kicad_sch]
2026-03-01 replaced .wrl with .step
    [aquarius-client-hw.kicad_pcb]
